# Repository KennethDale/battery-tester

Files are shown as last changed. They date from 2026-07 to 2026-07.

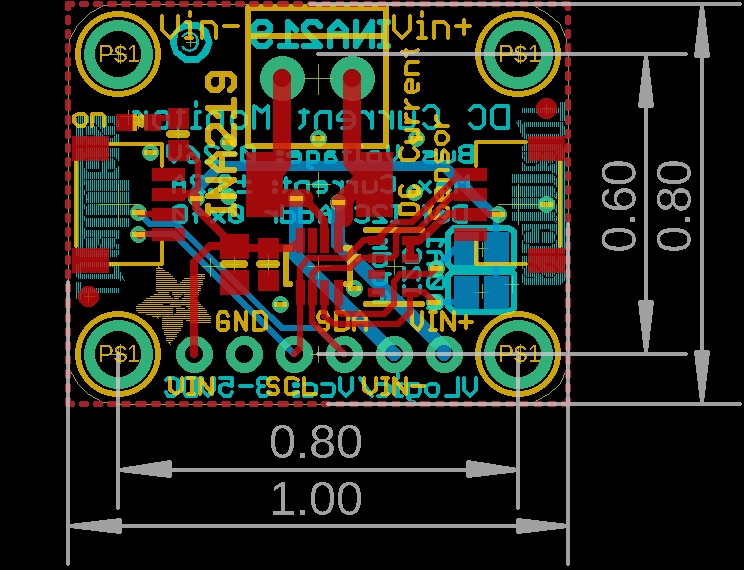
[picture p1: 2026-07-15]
models/adafruit_products_INA219_fab_print.jpeg

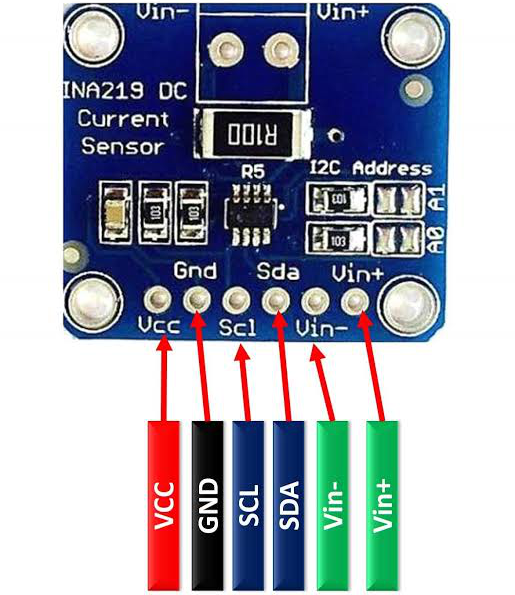
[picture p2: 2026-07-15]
models/ina219.jpeg

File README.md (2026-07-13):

# 🔋 ESP8266 Battery Capacity Logger

A simple, passive 5-channel battery capacity logger built around an ESP8266 and
INA219 current/voltage sensors. You connect a **pre-charged battery with a fixed
load** to each channel and the logger does the rest:

1. **Auto-detects** when a battery is connected (voltage rises above threshold)
2. **Logs** voltage, current, and accumulated capacity every 5 seconds
3. **Auto-stops** when the BMS disconnects the battery (voltage collapses)
4. **Displays** the final measured capacity (mAh) on a simple web interface

No charge/discharge control. No MOSFETs to drive. The ESP8266 just watches and
records — the battery's own BMS decides when the test is over.

> ⚠️ **Safety:** Lithium cells store a lot of energy. Always use cells with
> protection boards (BMS), appropriate load resistors, and fuses. Never leave
> discharging cells unattended.

---

## How it works

```
                 ┌──────────┐
  Battery+ ─────▶│ INA219   │─── Load Resistor ─── GND
                 │ (shunt)  │
  Battery- ─────▶│          │
                 └──────────┘
                      │ I2C (SDA/SCL)
                      ▼
                 ┌──────────┐
                 │ ESP8266  │ ── WiFi ──▶ Web UI
                 └──────────┘
```

Each INA219 sits between the battery and its load, measuring both voltage
(bus) and current (shunt). The ESP8266 polls all 5 sensors over I2C every 5
seconds, integrates the current into mAh, and watches for the BMS cutoff.

## Project layout

```
battery-tester/
├── platformio.ini            # PlatformIO build config
├── data/
│   └── index.html            # Web UI (self-contained, served from LittleFS)
├── src/
│   ├── main.cpp              # Entry point: I2C init, sampling loop
│   ├── config.h              # Compile-time tunables (intervals, thresholds)
│   ├── secrets.example.h     # Copy to secrets.h with your WiFi creds
│   └── (secrets.h)           # git-ignored
├── lib/
│   ├── BatteryChannel/       # INA219 wrapper + auto-detect state machine
│   ├── WebServer/            # HTTP routes (JSON/CSV API + static UI)
│   └── WifiManager/          # WiFi connect + soft-AP fallback
├── python/                   # Optional CLI companion
│   ├── battery_tester/
│   ├── tests/
│   ├── requirements.txt
│   └── pyproject.toml
└── docs/
    └── HARDWARE.md           # Wiring, INA219 address setup, BOM
```

## Requirements

| Tool | Version  | Notes |
| --- | --- | --- |
| PlatformIO  | ≥ 6.x | `pip install platformio` or `brew install platformio` |
| Python | ≥ 3.9 | Only needed for the companion CLI/tests |
| ESP8266 | NodeMCU 1.0 / Wemos D1 R2 or compatible |
| INA219 | 5× breakouts, each at a unique I2C address |

## Quick start (firmware)

```bash
# 1. Configure WiFi (optional — falls back to AP mode)
cp src/secrets.example.h src/secrets.h
# edit src/secrets.h with your SSID/password

# 2. Build + flash
pio run -t upload

# 3. Upload the web UI to LittleFS
pio run -t uploadfs

# 4. Watch the serial monitor for the IP address
pio device monitor
```

Then visit **http://batterylogger.local** (or the printed IP).

If you skip WiFi config, the board boots into AP mode — join the
`BatteryTester-XXXXXX` network and browse to `192.168.4.1`.

## Quick start (Python companion)

```bash
source .venv/bin/activate
pip install -e python

battery-tester status              # one-shot snapshot
battery-tester watch               # live-refreshing table (Ctrl-C to quit)
battery-tester export 0 -o run.csv # download channel 0 history
battery-tester reset 0             # clear channel 0 data
```

### Running the tests

```bash
pip install pytest
pytest python/tests
```

## HTTP API

| Method | Path | Description |
| --- | --- | --- |
| GET | `/` | Web UI (`index.html` from LittleFS) |
| GET | `/api/info` | Firmware, chip id, uptime, log interval  |
| GET | `/api/status` | JSON snapshot of **all** channels |
| GET | `/api/channel?n={n}` | JSON snapshot of one channel |
| POST | `/api/reset?n={n}` | Clear channel data, return to waiting |
| GET | `/api/history?n={n}` | CSV download of channel `n` history |

`n` is a 0-indexed channel number (0–4).

## Configuration

Tunable constants live in [`src/config.h`](src/config.h) and can be overridden
from `platformio.ini`'s `build_flags`:

| Define | Default | Meaning |
| --- | --- | --- |
| `NUM_CHANNELS` | 5 | Number of active channels |
| `LOG_INTERVAL_MS` | 5000 | How often to sample + record |
| `INA219_ADDRESSES` | 0x40–0x44 | I2C addresses of each INA219 |
| `SHUNT_OHMS` | 0.1 | Shunt resistance on the INA219 breakout |
| `MAX_CURRENT_A` | 3.2 | Max current for INA219 calibration |
| `CONNECT_THRESHOLD_V` | 2.5 | Voltage above this = battery connected |
| `DISCONNECT_THRESHOLD_V` | 2.0 | Voltage below this = BMS cutoff / done |
| `HISTORY_LENGTH` | 600 | Max samples per channel in RAM |

## Hardware

See [`docs/HARDWARE.md`](docs/HARDWARE.md) for wiring, INA219 address
configuration, and a bill of materials.

## License

MIT — see [`LICENSE`](LICENSE).

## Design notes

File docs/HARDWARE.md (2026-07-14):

# Hardware notes

This document describes the reference hardware for the passive INA219 battery
capacity logger. The default firmware supports up to 8 channels (0–7).

> ⚠️ **Lithium safety.** Use cells with protection boards (BMS). The BMS
> determines when the test ends by cutting off. Always include a fuse per
> channel.

## Wiring overview

```text
                     I2C Bus (shared)
   ESP8266 D1 (SCL) ──┬──┬──┬──┬──┬──┬──┬──┬──▶ INA219 #0..7 SCL
   ESP8266 D2 (SDA) ──┼──┼──┼──┼──┼──┼──┼──┼──▶ INA219 #0..7 SDA
   ESP8266 3.3V    ───┼──┼──┼──┼──┼──┼──┼──┼──▶ INA219 #0..7 VCC
   ESP8266 GND     ───┴──┴──┴──┴──┴──┴──┴──┴──▶ INA219 #0..7 GND
                        │  │  │  │  │  │  │  │
                        └──┴──┴──┴──┴──┴──┴──┴──▶ Battery- (all channels, see below)

  Per channel:
  Battery+ ──▶ INA219 Vin+ ──▶ INA219 Vin- ──▶ Load Resistor ──▶ Battery- ──▶ common GND
                     │
              (INA219 measures voltage & current here)
```

Each channel is identical: the battery connects through the INA219's shunt to
a fixed load resistor. The INA219 measures the bus voltage (battery voltage)
and the shunt voltage (proportional to current).

> ⚠️ **`Battery-` must be tied to the common GND net** (the same rail as the
> ESP8266 GND and INA219 GND pins). The INA219's bus voltage reading is
> Vin- measured *relative to its own GND pin*, not Vin+ minus Vin-. If the
> load-resistor return path isn't referenced to that shared ground, the bus
> voltage reads near 0V no matter what a multimeter shows across the battery
> terminals directly — the channel will stay stuck in `waiting` even with a
> battery connected.

## ESP8266 pin map (NodeMCU 1.0 / Wemos D1)

| GPIO  | NodeMCU pin | Role |
| ----- | --- | --- |
| GPIO5 | D1 | I2C SCL (all INA219s) |
| GPIO4 | D2 | I2C SDA (all INA219s) |
| 3.3V  | 3V3 | INA219 VCC |
| GND | GND | Common ground |

Only 2 GPIO pins are needed for all 8 channels — everything goes over I2C.

## INA219 address configuration

Each INA219 breakout has two address jumpers (A0, A1) that set its I2C address.
You need 8 unique addresses. The default addresses available are:

| A1 jumper | A0 jumper | I2C address | Channel | Notes |
| --- | --- | --- | --- | --- |
| GND | GND | 0x40 | 0 | default |
| GND | VS | 0x41 | 1 | A0 to pad |
| GND | SDA | 0x42 | 2 | |
| GND | SCL | 0x43 | 3 | |
| VS | GND | 0x44 | 4 | A1 to pad |
| VS | VS | 0x45 | 5 | A1 and A2 to pad |
| VS | SDA | 0x46 | 6 | |
| VS | SCL | 0x47 | 7 | |

Set these addresses on each breakout by soldering the A0/A1 pads according to
the breakout's silkscreen. Match the order to `INA219_ADDRESSES` in
`config.h`.

> **Pull-ups:** The I2C bus needs 4.7kΩ pull-up resistors on SDA and SCL.
> Many INA219 breakouts include them — if using 8 boards, only enable pull-ups
> on one (cut the traces on the other 7) to avoid overloading the bus.

## Load resistor sizing

Choose a load resistor appropriate for the cell and target discharge rate:

| Target current | Load resistor (at 3.7V) | Power rating |
| --- | --- | --- |
| 250 mA | ~15Ω | ≥ 1W |
| 500 mA | ~7.5Ω | ≥ 2W |
| 1 A | ~3.7Ω | ≥ 5W |

Use wirewound or ceramic power resistors. The resistor must dissipate
`P = I² × R` continuously — err on the side of a higher wattage rating.

## Bill of materials

| Part | Qty | Notes |
| --- | --- | --- |
| ESP8266 dev board | 1 | NodeMCU 1.0 or Wemos D1 R2 |
| INA219 breakout | 8 | Each at a unique I2C address (0x40–0x47) |
| Power resistor (load) | 8 | Sized for your target current |
| 18650 cell holder + BMS | 8 | Protected cells or add a protection board |
| Fuse (per channel) | 8 | ~2A polyfuse or glass fuse |
| 4.7kΩ resistor (I2C pull-up) | 2 | Only needed if breakouts lack pull-ups |
| Breadboard / perfboard | 1 | For wiring |

## How auto-detect works

The firmware uses two voltage thresholds (defined in `config.h`):

1. **`CONNECT_THRESHOLD_V` (2.5V)** — When voltage rises above this, the
   logger starts recording. This detects when you plug in a charged cell.

2. **`DISCONNECT_THRESHOLD_V` (2.0V)** — When voltage drops below this, the
   BMS has cut off the battery. The logger freezes the capacity reading and
   marks the channel as `COMPLETE`.

A typical li-ion BMS cuts off around 2.5V under load. The default 2.0V
threshold is conservative — you can raise it to match your BMS if needed.

## Calibration

The INA219 breakout comes with a 0.1Ω shunt resistor and is calibrated for
3.2A max by default. If your breakout has a different shunt, update
`SHUNT_OHMS` and `MAX_CURRENT_A` in `config.h`.

To verify calibration, connect a known load and compare the firmware's current
reading against a multimeter. Fine-tune the shunt value if needed.

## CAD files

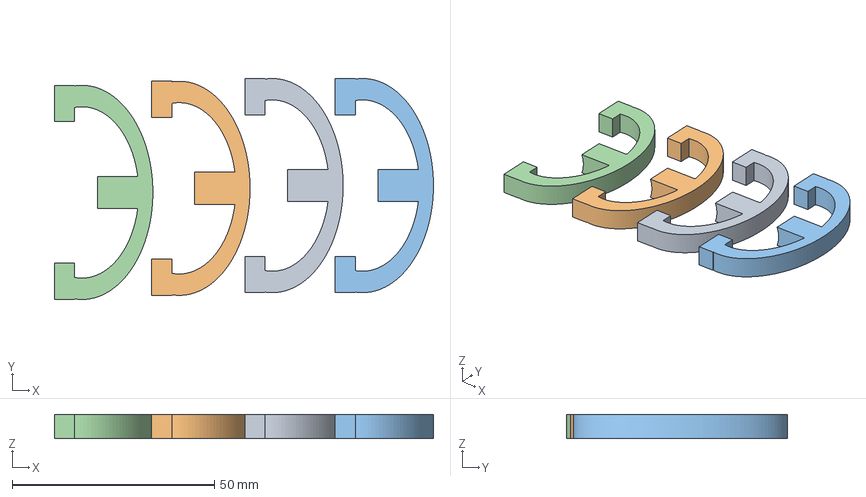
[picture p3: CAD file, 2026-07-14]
models/18350 holder.3mf
93.8 x 54.7 x 6.00 mm
18350 holder.stl x 4

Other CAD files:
models/18350 holder.blend
models/18350 holder.stl

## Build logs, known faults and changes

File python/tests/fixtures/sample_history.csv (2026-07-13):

elapsed_s | voltage | current_a
0 | 4.180 | 0.520
5 | 4.150 | 0.518
10 | 4.120 | 0.519
15 | 4.080 | 0.521
20 | 4.040 | 0.520
25 | 3.990 | 0.519
30 | 3.940 | 0.520
35 | 3.880 | 0.521
40 | 3.810 | 0.520
45 | 3.730 | 0.518
50 | 3.640 | 0.520
55 | 3.520 | 0.519
60 | 3.380 | 0.520
65 | 3.200 | 0.521
70 | 2.950 | 0.518
75 | 2.700 | 0.000

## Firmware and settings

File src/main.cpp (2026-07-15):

// ---------------------------------------------------------------------------
// 5-Channel Passive Battery Capacity Logger
// Target: ESP8266 (NodeMCU 1.0 / Wemos D1 R2)
//
// Each channel reads voltage/current from an INA219 sensor over I2C. A
// pre-charged battery with a fixed load attached is connected to each
// INA219. The logger:
//   * auto-detects when a battery is connected,
//   * logs voltage, current, and accumulated capacity every 5 seconds,
//   * stops when the BMS disconnects the battery (auto-detect),
//   * serves a simple web UI showing final capacity per channel.
// ---------------------------------------------------------------------------

#include <Arduino.h>
#include <Wire.h>
#include <LittleFS.h>
#include <ESP8266mDNS.h>
#include <coredecls.h>  // crc32()

#include "config.h"
#include "BatteryChannel.h"
#include "WebServer.h"
#include "WifiManager.h"

// --- I2C / INA219 setup ----------------------------------------------------
// ESP8266 default I2C: SCL=D1(GPIO5), SDA=D2(GPIO4). Each INA219 breakout
// needs a unique address set via its A0/A1 solder jumpers (0x40..0x4F).
static const uint8_t INA_ADDRESSES[NUM_CHANNELS] = INA219_ADDRESSES;

// --- Globals ---------------------------------------------------------------
BatteryChannel* channels = nullptr;
BatteryWebServer* webServer = nullptr;

// --- RTC snapshot ------------------------------------------------------------
// Channel state is mirrored into RTC user memory once per sample tick so an
// in-progress test survives a crash or watchdog reset. RTC memory is cleared
// by power loss; in that case channels that find a battery already connected
// at boot flag their test "interrupted" instead (see BatteryChannel::update).
struct RtcSnapshot {
    uint32_t magic;
    uint16_t version;
    uint16_t numChannels;
    ChannelSnapshot ch[NUM_CHANNELS];
    uint32_t crc;
};
static_assert(sizeof(RtcSnapshot) % 4 == 0, "RTC writes need 4-byte multiples");
static_assert(sizeof(RtcSnapshot) <= 512, "RTC user memory is 512 bytes");

static const uint32_t RTC_MAGIC = 0x42544C47;  // "BTLG"
static const uint16_t RTC_VERSION = 2;  // v2 adds ChannelSnapshot::startVoltage
static RtcSnapshot rtcSnap;

static void saveRtcSnapshot() {
    rtcSnap.magic = RTC_MAGIC;
    rtcSnap.version = RTC_VERSION;
    rtcSnap.numChannels = NUM_CHANNELS;
    for (uint8_t i = 0; i < NUM_CHANNELS; ++i) {
        channels[i].captureSnapshot(rtcSnap.ch[i]);
    }
    rtcSnap.crc = crc32(&rtcSnap, sizeof(rtcSnap) - sizeof(rtcSnap.crc));
    ESP.rtcUserMemoryWrite(0, reinterpret_cast<uint32_t*>(&rtcSnap), sizeof(rtcSnap));
}

static void restoreRtcSnapshot() {
    if (!ESP.rtcUserMemoryRead(0, reinterpret_cast<uint32_t*>(&rtcSnap), sizeof(rtcSnap))) {
        return;
    }
    if (rtcSnap.magic != RTC_MAGIC || rtcSnap.version != RTC_VERSION ||
        rtcSnap.numChannels != NUM_CHANNELS ||
        rtcSnap.crc != crc32(&rtcSnap, sizeof(rtcSnap) - sizeof(rtcSnap.crc))) {
        Serial.println(F("[boot] no valid RTC snapshot (cold boot)"));
        return;
    }
    uint8_t restored = 0;
    for (uint8_t i = 0; i < NUM_CHANNELS; ++i) {
        if (channels[i].restoreSnapshot(rtcSnap.ch[i])) ++restored;
    }
    Serial.printf("[boot] restored %u in-progress test(s) from RTC memory\n", restored);
}

// --- Helpers ---------------------------------------------------------------
static void scanI2C() {
    Serial.println(F("[i2c] scanning bus..."));
    uint8_t found = 0;
    for (uint8_t addr = 1; addr < 127; ++addr) {
        Wire.beginTransmission(addr);
        uint8_t err = Wire.endTransmission();
        if (err == 0) {
            Serial.printf("[i2c] device found at 0x%02X\n", addr);
            ++found;
        }
    }
    Serial.printf("[i2c] scan complete, %u device(s) found\n", found);
}

static BatteryChannel* makeChannels(const uint8_t addresses[], uint8_t count) {
    // Allocate raw storage, then construct each channel in place.
    void* mem = ::operator new[](sizeof(BatteryChannel) * count);
    BatteryChannel* arr = static_cast<BatteryChannel*>(mem);
    for (uint8_t i = 0; i < count; ++i) {
        new (&arr[i]) BatteryChannel(i, addresses[i]);
    }
    return arr;
}

// --- setup / loop ----------------------------------------------------------
void setup() {
    Serial.begin(BAUD_RATE);
    delay(100);
    Serial.println();
    Serial.println(F("[boot] battery logger starting"));

    // I2C for the INA219 sensors
    Wire.begin();
    Serial.println(F("[boot] I2C started"));
    scanI2C();

    // Mount LittleFS (web UI assets)
    if (!LittleFS.begin()) {
        Serial.println(F("[boot] LittleFS mount failed"));
    } else {
        Serial.println(F("[boot] LittleFS mounted"));
    }

    // Allocate channels dynamically so NUM_CHANNELS can be changed without
    // editing the initializer list.
    channels = makeChannels(INA_ADDRESSES, NUM_CHANNELS);

    // Initialize each INA219
    uint8_t found = 0;
    for (uint8_t i = 0; i < NUM_CHANNELS; ++i) {
        if (channels[i].begin()) {
            ++found;
        }
    }
    Serial.printf("[boot] %u/%u INA219 sensors found\n", found, NUM_CHANNELS);

    restoreRtcSnapshot();

    connectWifi();

    if (MDNS.begin("batterylogger")) {
        MDNS.addService("http", "tcp", 80);
        Serial.println(F("[boot] mDNS: http://batterylogger.local"));
    }

    webServer = new BatteryWebServer(channels, NUM_CHANNELS);
    webServer->begin();
    Serial.println(F("[boot] ready"));
}

void loop() {
    static unsigned long lastTick = 0;
    unsigned long now = millis();

    // Sample every channel at the configured interval
    if (now - lastTick >= SAMPLE_INTERVAL_MS) {
        lastTick = now;
        for (uint8_t i = 0; i < NUM_CHANNELS; ++i) {
            channels[i].update();
        }
        // Mirror state to RTC memory so tests survive a crash/watchdog reset.
        saveRtcSnapshot();
    }

    webServer->loop();
    MDNS.update();
}

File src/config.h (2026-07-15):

#ifndef BATTERY_TESTER_CONFIG_H
#define BATTERY_TESTER_CONFIG_H

// ---------------------------------------------------------------------------
// Configuration for the passive INA219 battery capacity logger.
// Override any of these via PlatformIO build_flags if needed.
// ---------------------------------------------------------------------------

#ifndef NUM_CHANNELS
#define NUM_CHANNELS 8
#endif

#ifndef BAUD_RATE
#define BAUD_RATE 115200
#endif

// How often to sample each channel (milliseconds). The firmware samples the
// INA219 every second and decides whether to push a history entry based on
// voltage change or a maximum quiet period.
#ifndef SAMPLE_INTERVAL_MS
#define SAMPLE_INTERVAL_MS 1000
#endif

// Minimum voltage change (volts) that triggers a new history entry.
#ifndef LOG_VOLTAGE_DELTA_V
#define LOG_VOLTAGE_DELTA_V 0.05f
#endif

// Maximum time between history entries when the voltage is stable (ms).
#ifndef LOG_MAX_QUIET_MS
#define LOG_MAX_QUIET_MS 60000
#endif

// --- INA219 I2C addresses --------------------------------------------------
// Each INA219 breakout must have a unique address set via its A0/A1 jumpers.
// Default addresses from the datasheet (0x40..0x45); change to match your
// board wiring.
#ifndef INA219_ADDRESSES
#define INA219_ADDRESSES {0x40, 0x41, 0x42, 0x43, 0x44, 0x45, 0x46, 0x47}
#endif

// INA219 calibration: shunt resistance in ohms and max current in amps.
// These match the common blue INA219 breakout (0.1 ohm, 3.2A max).
#ifndef SHUNT_OHMS
#define SHUNT_OHMS 0.1f
#endif

#ifndef MAX_CURRENT_A
#define MAX_CURRENT_A 3.2f
#endif

// --- Auto-detect thresholds ------------------------------------------------
// A reading above this means a battery is connected and we should start
// logging. Li-ion cells sit around 3.0–4.2V; use a conservative floor.
#ifndef CONNECT_THRESHOLD_V
#define CONNECT_THRESHOLD_V 2.5f
#endif

// A reading below this means the BMS has disconnected the battery and the
// test is complete. The cell's protection board cuts off around 2.5–2.9V.
#ifndef DISCONNECT_THRESHOLD_V
#define DISCONNECT_THRESHOLD_V 2.0f
#endif

// Consecutive samples required past a threshold before a state transition.
// Filters single-sample noise/contact bounce so one glitched reading can't
// start, stop, or wipe a test.
#ifndef DEBOUNCE_SAMPLES
#define DEBOUNCE_SAMPLES 3
#endif

// If the voltage recovers after the channel has sat in LOW_VOLTAGE longer
// than this, assume a fresh battery was connected and start a new test
// instead of adding to the previous battery's totals.
#ifndef LOW_VOLTAGE_NEW_TEST_MS
#define LOW_VOLTAGE_NEW_TEST_MS 600000UL
#endif

// A reconnect voltage this far above the last healthy voltage also counts
// as a fresh battery (e.g. 4.1V after a cell that sagged to 3.0V).
#ifndef NEW_TEST_VOLTAGE_JUMP_V
#define NEW_TEST_VOLTAGE_JUMP_V 0.8f
#endif

// A battery detected within this long after boot was connected before the
// device started (e.g. power loss mid-test): flag the test "interrupted"
// so its capacity total isn't trusted blindly.
#ifndef BOOT_CONNECT_GRACE_MS
#define BOOT_CONNECT_GRACE_MS 15000UL
#endif

// --- Early final-capacity estimate -----------------------------------------
// Predict the final delivered capacity (mAh) from the pack voltage at the very
// start of the discharge: final_mAh ~= SLOPE * V0 + INTERCEPT. Fit by
// leave-one-out cross-validation over the 13 clean runs in results/ (see
// results/capacity_estimator.py); median error ~7%. Because these cells have a
// flat voltage plateau under constant-current load, the first minutes of the
// curve add no information over V0 alone, so the estimate is available as soon
// as a test starts. It is only trustworthy while V0 sits in the calibrated
// band [V0_MIN, V0_MAX]; outside it the estimate is reported as invalid.
#ifndef CAPACITY_ESTIMATE_SLOPE_MAH_PER_V
#define CAPACITY_ESTIMATE_SLOPE_MAH_PER_V 1228.6f
#endif
#ifndef CAPACITY_ESTIMATE_INTERCEPT_MAH
#define CAPACITY_ESTIMATE_INTERCEPT_MAH (-3486.5f)
#endif
// Energy estimate uses the same V0 model: final_Wh ~= SLOPE * V0 + INTERCEPT
// (LOOCV median error ~7%, same 13 runs).
#ifndef ENERGY_ESTIMATE_SLOPE_WH_PER_V
#define ENERGY_ESTIMATE_SLOPE_WH_PER_V 4.1342f
#endif
#ifndef ENERGY_ESTIMATE_INTERCEPT_WH
#define ENERGY_ESTIMATE_INTERCEPT_WH (-11.8516f)
#endif
#ifndef CAPACITY_ESTIMATE_V0_MIN
#define CAPACITY_ESTIMATE_V0_MIN 3.0f
#endif
#ifndef CAPACITY_ESTIMATE_V0_MAX
#define CAPACITY_ESTIMATE_V0_MAX 3.6f
#endif

// Web server port
#ifndef WEB_SERVER_PORT
#define WEB_SERVER_PORT 80
#endif

// Max history samples per channel (kept in RAM). 300 samples is sized for
// ~1.25 hours of change-driven logging. The first 60 slots preserve the
// initial 15 minutes; the remaining 240 slots form a ring for recent samples.
#ifndef HISTORY_LENGTH
#define HISTORY_LENGTH 300
#endif
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

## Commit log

2026-07-13 Initial commit: ESP8266 5-channel battery tester scaffold
    - PlatformIO firmware for ESP8266 (NodeMCU/Wemos D1)
    - Per-channel BatteryChannel model + state machine
    - Web UI served from LittleFS with JSON/CSV HTTP API
    - WiFi manager with soft-AP fallback
    - Python companion CLI (status/watch/start/stop/export) + tests
    - README, hardware docs, LICENSE
    [sample_history.csv]
2026-07-13 Simplify to passive INA219 battery capacity logger
    [18350 holder.blend, 18350 holder.stl, sample_history.csv]
2026-07-14 feat(firmware): expand support to 8 channels and optimize memory usage
    Increases the maximum number of supported battery channels from 5 to 8.
    This change involves updating the hardware configuration, I2C address
    mapping, and the web interface to accommodate the additional channels.
    Key changes:
    - firmware:
    - Increased `NUM_CHANNELS` to 8 in `config.h` and `platformio.ini`.
    - Implemented dynamic allocation for `BatteryChannel` objects to
    support variable channel counts without large static arrays.
    - Optimized RAM usage by switching history buffers from `float` to
    fixed-point `int16_t` (millivolts/milliamps) and reducing
    `HISTORY_LENGTH` from 600 to 400.
    - Added sensor co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
    [18350 holder.3mf, 18350 holder.blend, 18350 holder.stl]
2026-07-15 feat(firmware): implement RTC state persistence and advanced logging
    Refactor the battery logging logic to improve reliability, memory
    management, and data integrity on the ESP8266.
    - Implement RTC memory snapshotting to allow in-progress tests to
    survive watchdog resets or crashes.
    - Transition from fixed-interval logging to change-driven logging
    (voltage delta or quiet timeout) to optimize history density.
    - Implement chunked CSV streaming in the web server to prevent heap
    exhaustion during large file downloads.
    - Add debouncing logic to state transitions to filter sensor noise.
    - Introduce 'interrupted' and 'low_voltage' states to better track
    test validity.
    - Update web UI with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
    [config.h, main.cpp]
2026-07-15 feat(firmware): implement early capacity estimation and refactor integration
    Add functionality to estimate the final battery capacity (mAh) based on
    the initial voltage (V0) at the start of a discharge test. This allows
    for early prediction of test results.
    Changes include:
    - Firmware:
    - Added `startVoltage` to `ChannelSnapshot` and `BatteryChannel`.
    - Implemented `estimatedFinalCapacityMah()` using a linear model
    (slope/intercept) defined in `config.h`.
    - Refactored capacity integration to use a centralized `capacityIncrementMah`
    method with a `static_assert` to prevent unit scaling regressions.
    - Updated RTC version to v2 to accommodate the new snapshot field.
    - Added `e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
    [config.h, main.cpp]
2026-07-15 feat(ui): add energy (Wh) estimation to web and CLI displays
    Extend the early capacity estimation feature to include predicted final
    energy (Wh) across all interfaces.
    - Implemented `estimatedFinalEnergyWh()` in `BatteryChannel` using
    newly defined slope/intercept constants.
    - Added `estimated_capacity_wh` to JSON serialization.
    - Added energy estimation constants to `config.h`.
    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
